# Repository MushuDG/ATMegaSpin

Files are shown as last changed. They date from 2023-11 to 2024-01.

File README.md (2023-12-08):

> [!WARNING]  
> Hey! This project is still a Work in Progress. Files, instructions, and other stuff might change!

# Table of contents
1. [Goal of the game](#goal-of-the-game)
2. [PCB Pictures](#pcb-pictures)
    1. [Front](#front)
    2. [Back](#back)
3. [Schematics](#schematics)
    1. [Electrical schematic](#electrical-schematic)
    2. [PCB schematic](#pcb-schematic)
    3. [Mechanical schematic](#mechanical-schematic)
    4. [ATMega328P Pinout](#atmega328p-pinout)
4. [GERBER - 3D printed Files - Other Hardware stuff](#gerber---3d-printed-files---other-hardware-stuff)
    1. [3D Printed parts](#3d-printed-parts)
    2. [PCB GERBER File](#pcb-gerber-file)
    3. [Electrical parts](#electrical-parts)
5. [Installation](#installation)
    1. [Burn bootloader](#burn-bootloader)
        1. [Needed tools](#needed-tools)
        2. [Circuit](#circuit)
        3. [Pinout](#pinout)
        4. [Upload ISP sketch](#upload-isp-sketch)
        5. [Burn bootloader](#burn-bootloader-1)
            1. [Installing Mini-core](#installing-mini-core)
            2. [Select your device, crystal and programmer and burn bootloader](#select-your-device-crystal-and-programmer-and-burn-bootloader)
    2. [Upload sketch from programmer](#upload-sketch-from-programmer)
6. [Contributions](#contributions)
7. [License](#license)

# ATMegaSpin
## Goal of the game:
A LED game where the player has to press a button at the right moment to reach a specific goal. The challenge of the game lies in the speed at which the LEDs blink, the reduction of this speed with each achieved goal, and the necessity to press the button at the right moment to advance in the game.

## PCB Pictures:
### Front
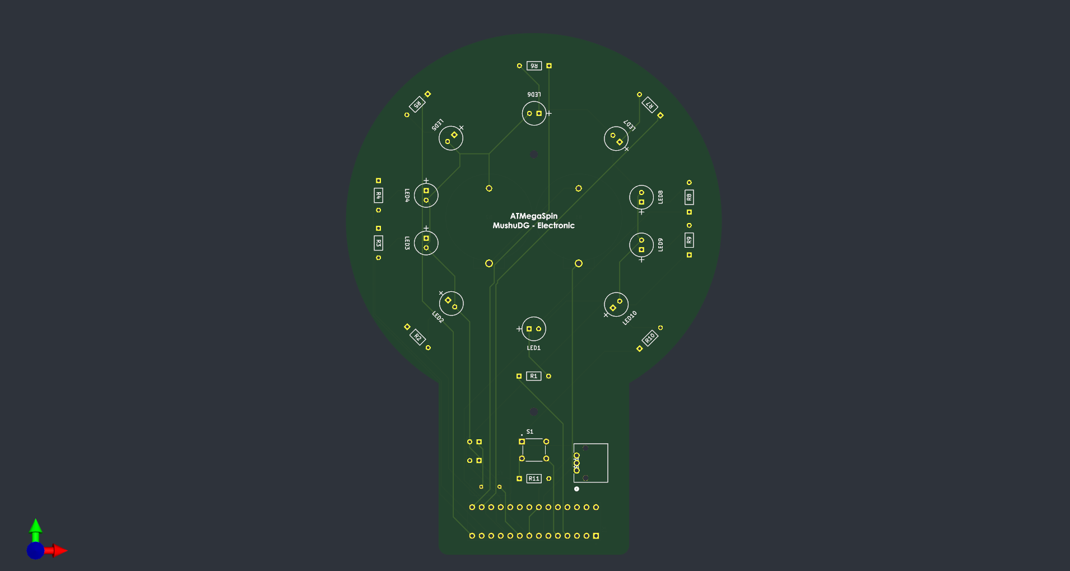
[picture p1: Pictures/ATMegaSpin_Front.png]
Front PCB view

### Back
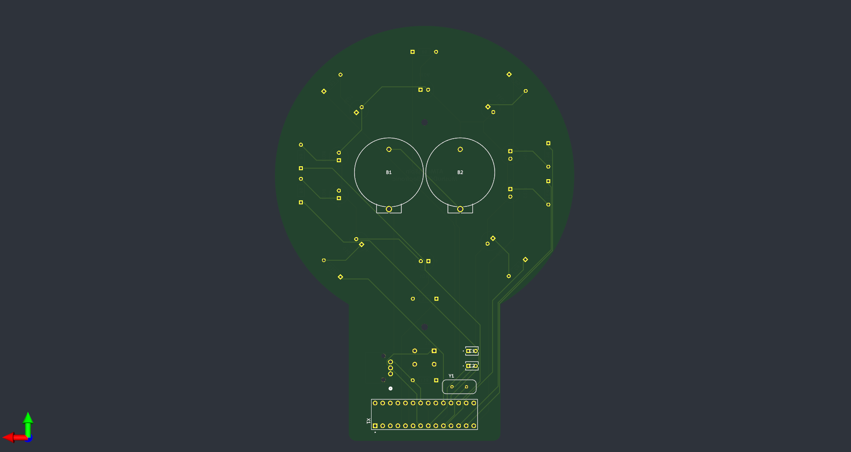
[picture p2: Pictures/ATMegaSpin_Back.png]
Back PCB view


# Schematics
## Electrical schematic:
[Electrical schematic](https://github.com/MushuDG/ATMegaSpin/blob/main/PDF/ATMegaSpin_Schematic.pdf)

## PCB schematic:
[PCB schematic](https://github.com/MushuDG/ATMegaSpin/blob/main/PDF/ATMegaSpin_PCB.pdf)

## Mechanical schematic:
[Mechanical schematic](https://github.com/MushuDG/ATMegaSpin/blob/main/PDF/EnsemblePCB.pdf)

## ATMega328P Pinout:
| Arduino Pinout | Electrical Part | ATMega328 Pinout | ATMega328 Pinout | Electrical Part | Arduino Pinout |
| --- | --- | --- | --- | --- | --- |
| Reset | Not used | 1 | 28 | Not used | A5 |
| D0 RX | Not used | 2 | 27 | Not used | A4 |
| D1 TX | Not used | 3 | 26 | Not used | A3 |
| D2 | LED 1 | 4 | 25 | Not used | A2 |
| D3 | Button Pin 4 | 5 | 24 | Not used | A1 |
| D4 | LED 2 | 6 | 23 | Not used | A0 |
| VCC | +5V | 7 | 22 | GND | GND |
| GND | GND | 8 | 21 | Not used | Aref |
| Crystal | Crystal | 9 | 20 | Not used | Avcc |
| Crystal | Crystal | 10 | 19 | LED 10 | D13 |
| D5 | Not used | 11 | 18 | LED 9 | D12 |
| D6 | LED 3 | 12 | 17 | LED 8 | D11 |
| D7 | LED 4 | 13 | 16 | LED 7 | D10 |
| D8 | LED 5 | 14 | 15 | LED 6 | D9 |

# GERBER - 3D printed Files - Other Hardware stuff
## 3D Printed parts:
[3D Printed parts](https://www.printables.com/fr/model/649943-atmegaspin)

## PCB GERBER File:
[PCB GERBER File](https://github.com/MushuDG/ATMegaSpin/blob/main/KiCad/ATMegaSpin/ATMegaSpin-GERBER.zip)

## Electrical parts:
| N° | PRODUCTS DETAILS | SUPPLIER | QUANTITY | PRICE | TOTAL |
| -- | --- | --- | --- | --- | --- |
| 1  | ED3050-5-ND‎<br>ED281DT‎<br>CONN IC DIP SOCKET 28POS TIN | Digikey  | 5 | Fr. 0.40000 | Fr. 2.00000  |
| 2  | ATMEGA328P-PU-ND‎‎<br>ATMEGA328P-PU‎<br>IC MCU 8BIT 32KB FLASH 28DIP | Digikey  | 5 | Fr. 2.60000 | Fr. 13.00000 |
| 3  | 2223-TS02-66-60-BK-160-SCR-D-ND‎<br>TS02-66-60-BK-160-SCR-D‎<br>6 X 6 MM, 6 MM ACTUATOR HEIGHT, | Digikey  | 5 | Fr. 0.09000 | Fr. 0.45000  |
| 4  | 50-ECS-160-18-4X-CKM-ND‎<br>ECS-160-18-4X-CKM‎<br>CRYSTAL 16.0000MHZ 18PF TH | Digikey  | 5 | Fr. 0.41000 | Fr. 2.05000  |
| 5  | BC1005CT-ND‎<br>‎K220J15C0GF5TL2‎<br>CAP CER 22PF 50V C0G/NP0 RADIAL | Digikey  | 10 | Fr. 0.15500 | Fr. 1.55000  |
| 6  | BS-7-ND‎<br>BS-7‎<br>BATT HLDR COIN 20MM 1 CEL PC PIN | Digikey  | 10 | Fr. 0.84100 | Fr. 8.41000  |
| 7  | CF18JT200RCT-ND‎<br>‎CF18JT200R‎<br>RES 200 OHM 5% 1/8W AXIAL | Digikey  | 50 | Fr. 0.02260 | Fr. 1.13000  |
| 8  | ‎516-1325-ND‎<br>‎HLMP-4700‎<br>LED RED DIFFUSED T-1 3/4 T/H | Digikey  | 50 | Fr. 0.34600 | Fr. 17.30000 |
| 9  | MFS101D-6-Z | Digikey  | 5 | Fr. 1.52000 | Fr. 7.60000  |
| 10 | PCB JLCPCB | JLCPCB | 5 | Fr. 1.84000 | Fr. 9.20000  |
| | | | | | |
| | Aprox. Total | | | | Fr. 62.69 |
| | Aprox. Total/pcs | | | | Fr. 12.54 |

# Prototype
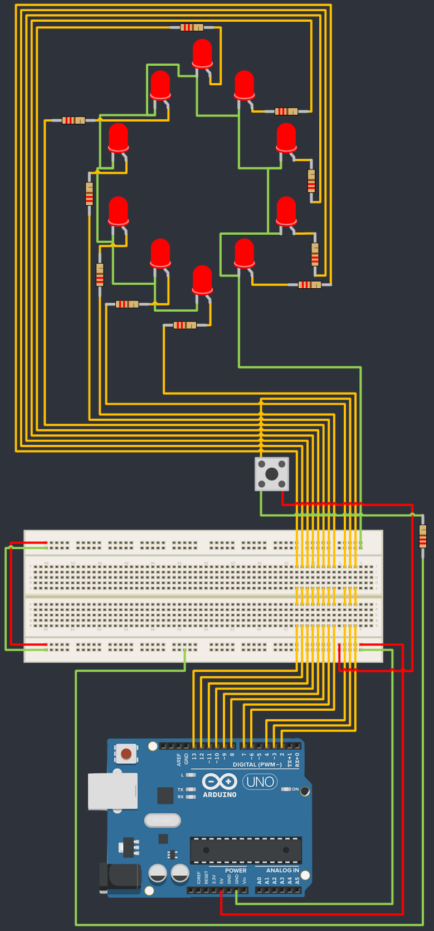
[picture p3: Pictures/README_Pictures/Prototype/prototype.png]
Prototype


# Installation
Before you can connect the [ATMega328P](https://en.wikipedia.org/wiki/ATmega328) microcontroller to the circuit, it's necessary to burn the bootloader of the chip. Once the bootloader is burned, the program can be uploaded to it.

*"To program the bootloader and provide to the microcontroller the compatibility with the Arduino Software (IDE) you need to use an In-circuit Serial Programmer (ISP) that is the device that connects to a specific set of pins of the microcontroller to perform the programming of the whole flash memory of the microcontroller, bootloader included. The ISP programming procedure also includes the writing of fuses: a special set of bits that define how the microcontroller works under specific circumstances."*

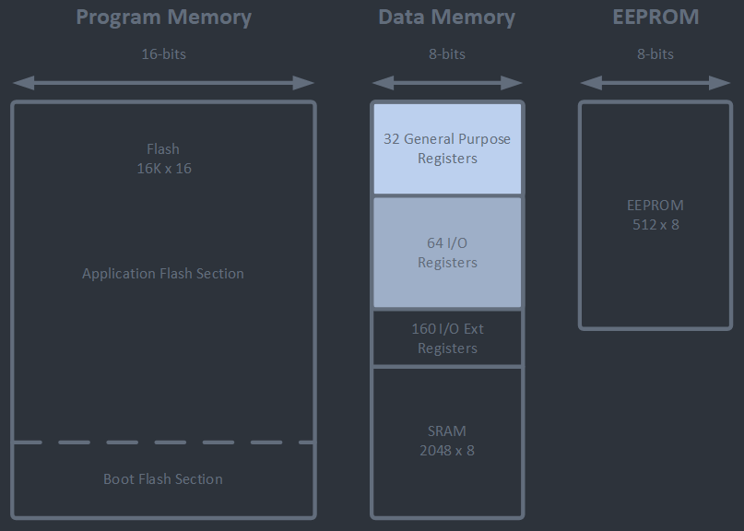
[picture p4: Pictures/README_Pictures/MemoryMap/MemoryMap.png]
Memory Map

The Memory Map of an ATmega328P

> [!IMPORTANT]  
> The preceding paragraph and illustration were taken from this documentation: [Arduino as ISP and Arduino Bootloaders](https://docs.arduino.cc/built-in-examples/arduino-isp/ArduinoISP) -  Accessed on 2023-11-22

## Burn bootloader
### Needed tools
To burn the bootloader on the microcontroller you need 2 arduino (In this case I use Arduino UNO) cards. The first will be used as an ISP programmer.

### Circuit
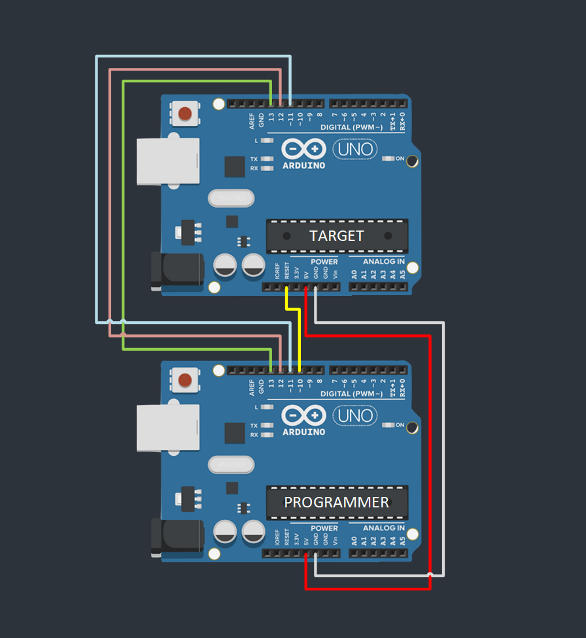
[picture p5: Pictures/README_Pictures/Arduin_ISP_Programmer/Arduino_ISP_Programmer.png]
Arduino ISP Programmer circuit


### Pinout
| Arduino Programmer Pin | Arduino Target Pin |
| --- | --- |
| +5 [V] | +5 [V] |
| GND | GND |
| D10 | Reset |
| 11 | 11 |
| 12 | 12 |
| 13 | 13 |

### Upload ISP sketch
Once the circuit is connected, follow the following instructions to apply the ISP programming sketch on the Arduino programmer:
1. Open the Arduino IDE and from the menu *File > Examples > 11.ArduinoISP > ArduinoISP*, load the sketch.
2. Select the proper board (I.E.: Arduino Uno) and upload the sketch

### Burn bootloader
#### Installing Mini-core
1. Open up the Arduino IDE and navigate to the preferences (or press ctrl+,). Copy the following URL into the empty field labelled *‘Additional Boards Manager URLs’*: [https://mcudude.github.io/MiniCore/package_MCUdude_MiniCore_index.json](https://mcudude.github.io/MiniCore/package_MCUdude_MiniCore_index.json)
2. Go to the boards manager, which can be found under *Tools > Board > Boards Manager*.
Type *‘minicore’* into the search bar and the relevant entry will appear. Select the latest version and click *‘install’*. Once the installation is complete, close the boards manager window.

#### Select your device, crystal and programmer and burn bootloader
1. Select the relevant device, crystal and programmer options under the *‘tools’* menu.
2. Under board, select *‘ATmega328’* (or whichever chip you’re using).
3. Under clock, select the frequency of your external clock. It should be written in block capitals on the top of the crystal’s casing.
4. Set your programmer as *‘Arduino as ISP’*
5. Burn the bootloader using the *‘Burn Bootloader’* option at the bottom of the Tools menu.

## Upload sketch from programmer
Once the bootloader is burned, open up the *[Spin.ino](https://github.com/MushuDG/ATMegaSpin/blob/main/Code/Spin/Spin.ino)* sketch. From the menu *Sketch* use the *Upload Using Programmer* tool to Upload the sketch to the ATMega328P Target.

Then, you can disconnect the MCU from the Arduino target and clip it to your circuit. 

## Contributions

Contributions to this project are welcome! If you have ideas for improvements or bug fixes, please follow the [contribution guidelines](CONTRIBUTING.md).

1. Fork the project.
2. Create your feature branch: `git checkout -b feature/AmazingFeature`.
3. Commit your changes: `git commit -m 'Add some amazing feature'`.
4. Push to the branch: `git push origin feature/AmazingFeature`.
5. Open a pull request.

## License

This project is licensed under the  AGPL-3.0 license - see the [LICENSE](LICENSE) file for details.

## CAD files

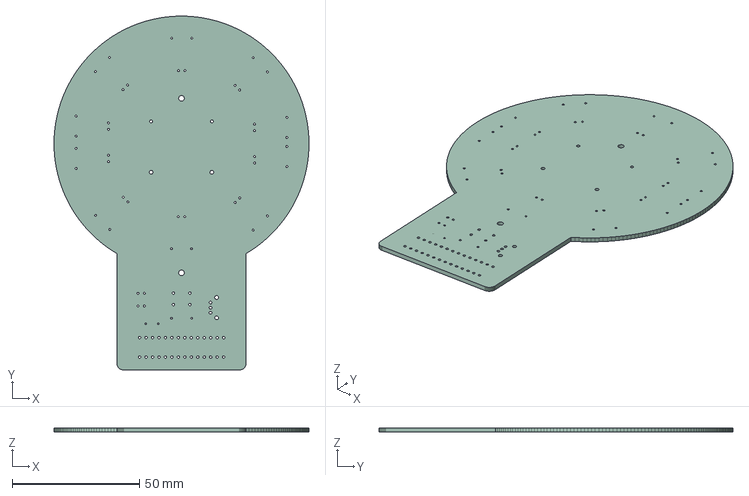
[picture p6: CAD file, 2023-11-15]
3DModel/ATMegaSpin.step
100.2 x 139.0 x 1.60 mm

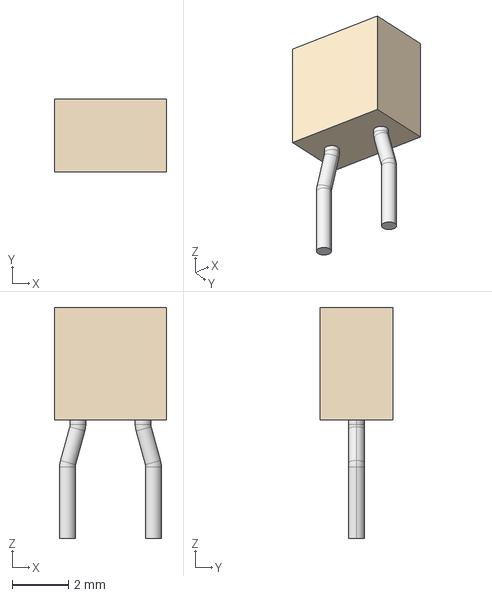
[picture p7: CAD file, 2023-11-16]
3DModel/Parts/CAP_K-SERIES_15-L2_VIS.step
3.99 x 2.59 x 8.20 mm

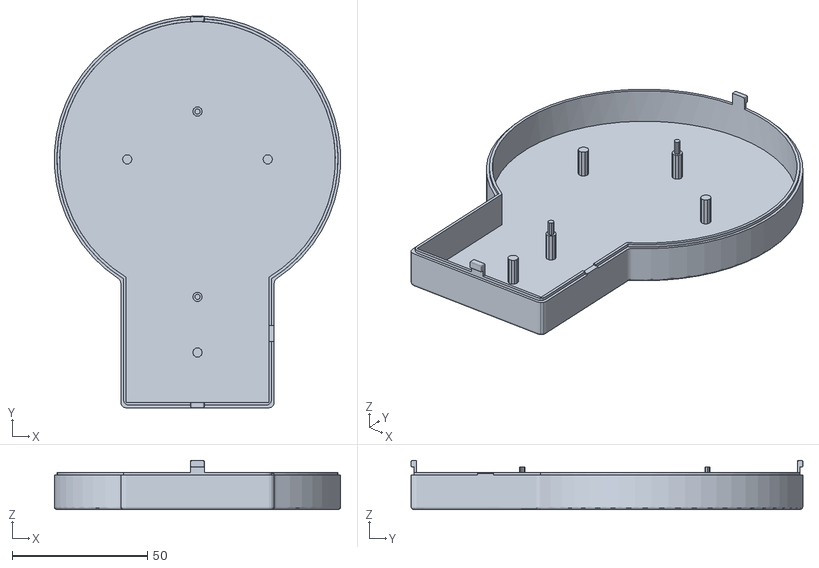
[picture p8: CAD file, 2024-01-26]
Inventor/STL/BottomBox.stl
105.8 x 145.0 x 18.2

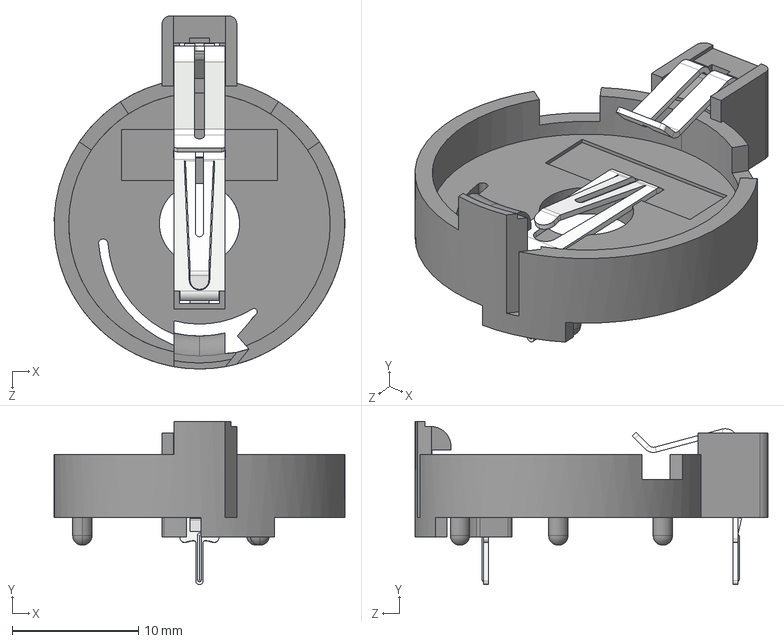
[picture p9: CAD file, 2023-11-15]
KiCad/ATMegaSpin/1066/1066.step
23.0 x 12.9 x 27.9 mm

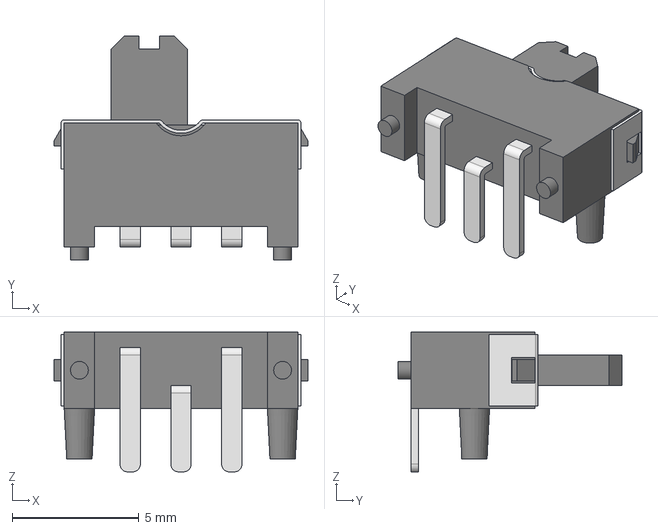
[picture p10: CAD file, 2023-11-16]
3DModel/Parts/MFS101D-6-Z.stp
10.0 x 8.80 x 5.50 mm
MFS101D61_bu
MFS101D-6-Z_b

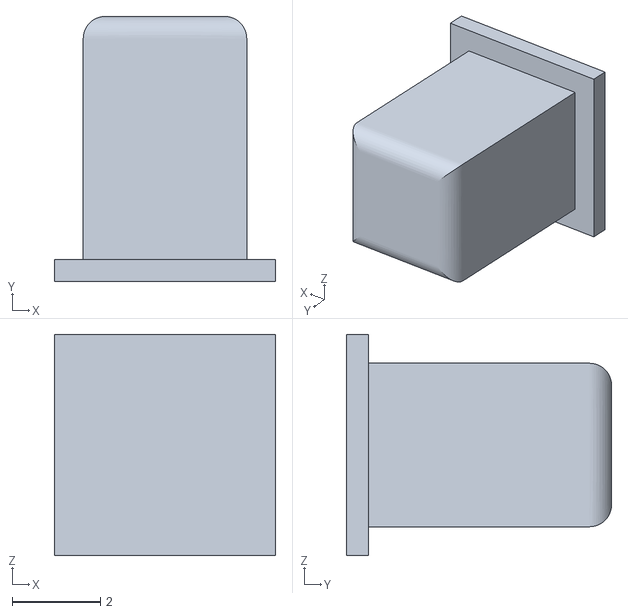
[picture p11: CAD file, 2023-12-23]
Inventor/button v3.stl
5.00 x 6.00 x 5.00

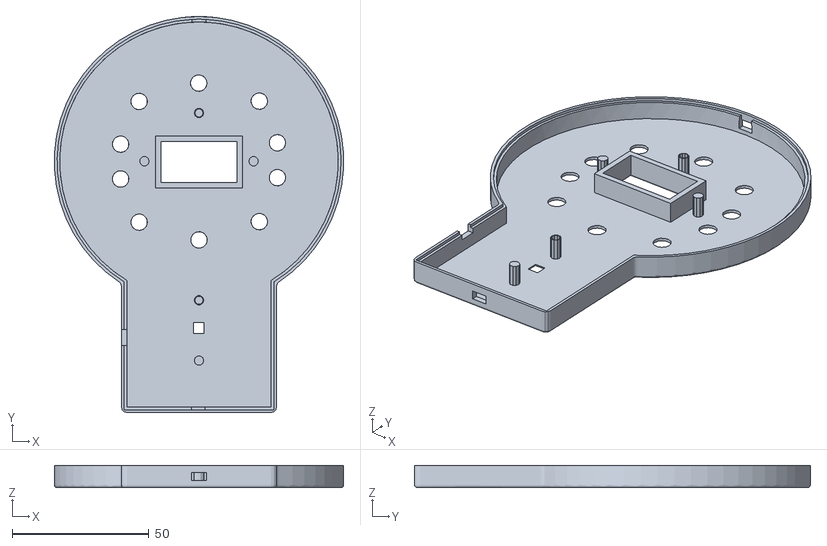
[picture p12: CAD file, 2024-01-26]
Inventor/STL/TopBox.stl
105.8 x 145.0 x 8.20

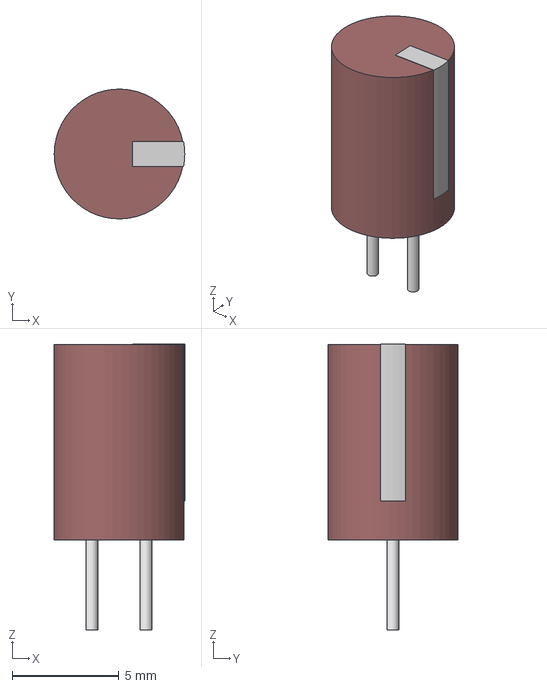
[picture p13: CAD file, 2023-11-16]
3DModel/Parts/LED_HLMP-47XX_BRA.step
6.13 x 6.09 x 13.4 mm

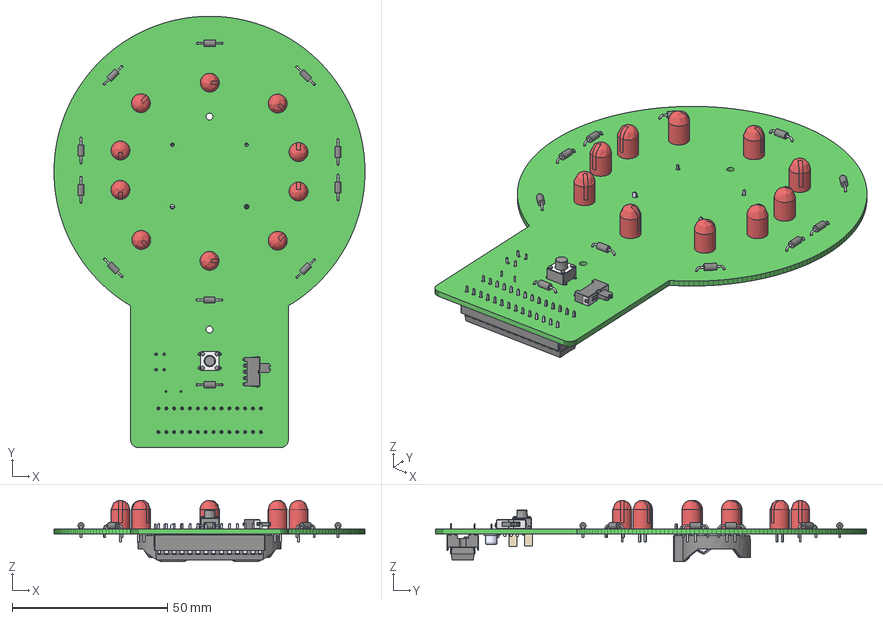
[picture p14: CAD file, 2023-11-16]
Inventor/EnsemblePCB.stp
100.2 x 139.0 x 19.8 mm
ATMegaSpin
BS-7 x 2
ED281DT
ATMEGA328-PU
ECS-80-18-4XDN
product
product_1
product_2 x 11
product_3 x 10
CUI_DEVICES_TS02-66-60-BK-160-SCR-D
MFS101D-6-Z

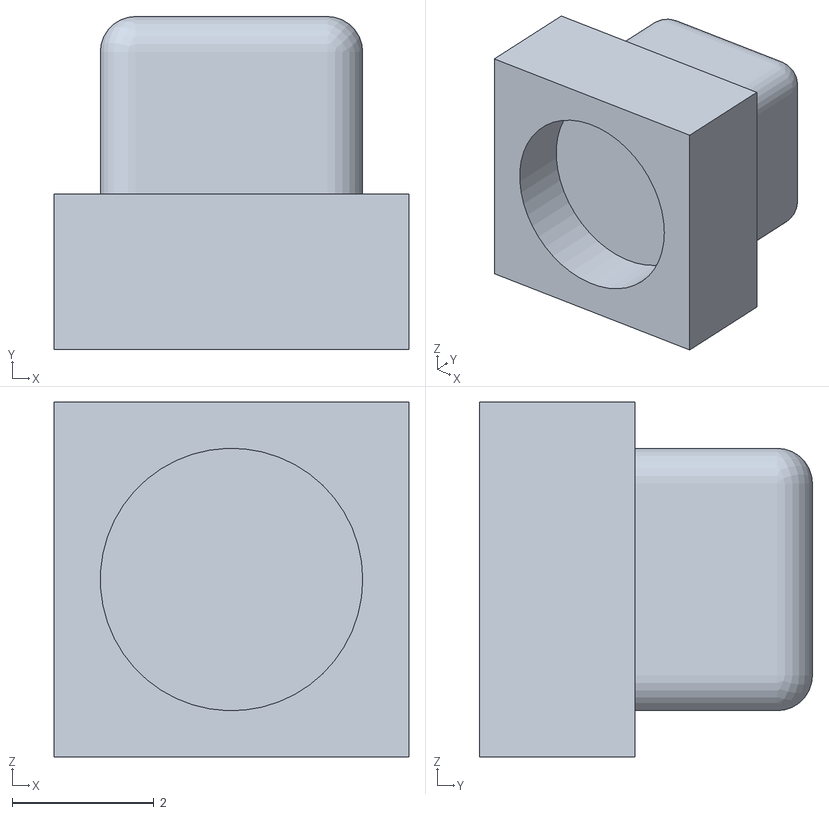
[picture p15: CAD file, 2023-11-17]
Inventor/STL/button.stl
5.00 x 4.70 x 5.00

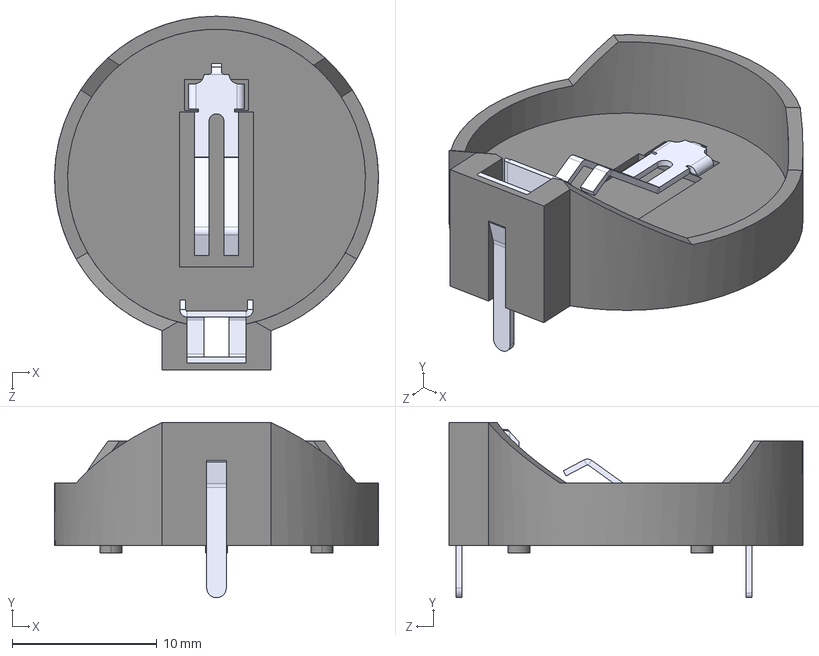
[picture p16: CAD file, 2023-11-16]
3DModel/Parts/BS-7--3DModel-STEP-1.STEP
22.3 x 12.1 x 24.4 mm

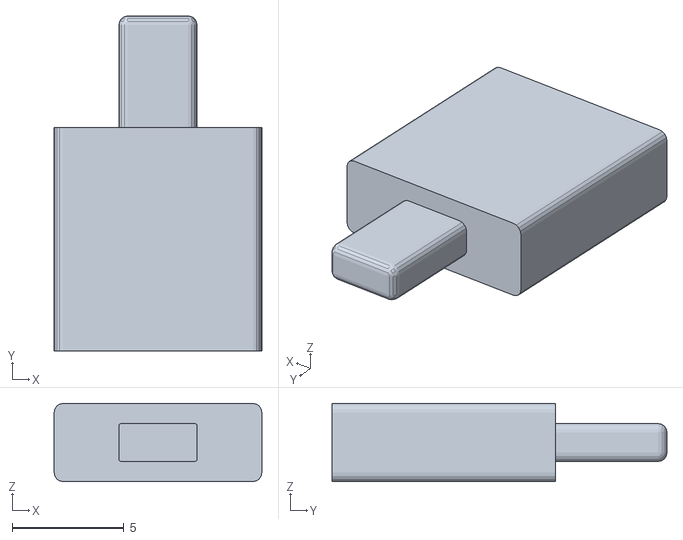
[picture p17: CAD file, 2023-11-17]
Inventor/STL/SwitchOnOff.stl
9.30 x 15.0 x 3.50

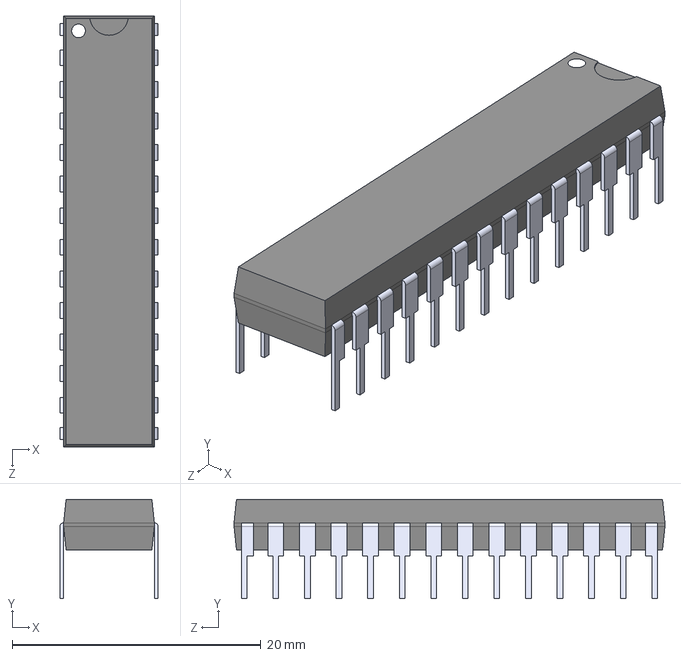
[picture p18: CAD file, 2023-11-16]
3DModel/Parts/ATMEGA328P-PU.step
7.90 x 8.00 x 34.7 mm

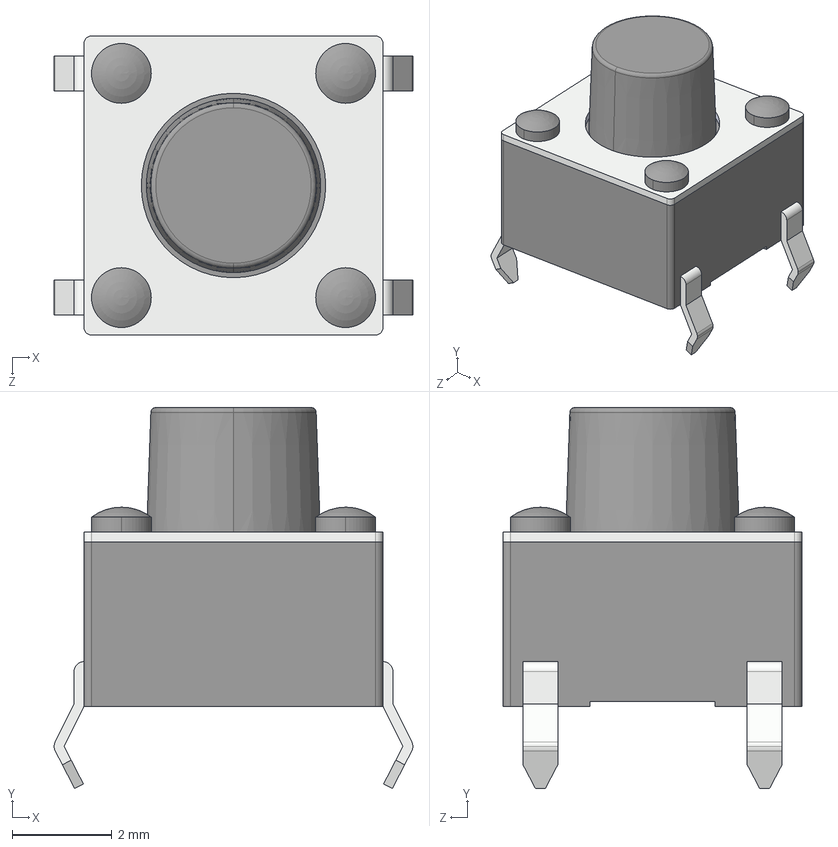
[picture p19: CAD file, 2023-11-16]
3DModel/Parts/CUI_DEVICES_TS02-66-60-BK-160-SCR-D.step
7.20 x 7.65 x 6.00 mm

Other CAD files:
3DModel/Parts/STA_CF18_STP.step
3DModel/Parts/ECS-160-18-4X-CKM.step
3DModel/Parts/ED281DT.step
Inventor/button v2.stl
3DModel/ATMegaSpin/ATMegaSpin.ipt
3DModel/Parts/ATMEGA328P-PU/ATMEGA328P-PU.ipt
3DModel/Parts/BS-7--3DModel-STEP-1/BS-7--3DModel-STEP-1.ipt
3DModel/Parts/CAP_K-SERIES_15-L2_VIS/CAP_K-SERIES_15-L2_VIS.ipt
3DModel/Parts/CUI_DEVICES_TS02-66-60-BK-160-SCR-D/CUI_DEVICES_TS02-66-60-BK-160-SCR-D.ipt
3DModel/Parts/ECS-160-18-4X-CKM/ECS-160-18-4X-CKM.ipt
3DModel/Parts/ED281DT/ED281DT.ipt
3DModel/Parts/LED_HLMP-47XX_BRA/LED_HLMP-47XX_BRA.ipt
3DModel/Parts/MFS101D-6-Z/MFS101D-6-Z.ipt
3DModel/Parts/STA_CF18_STP/STA_CF18_STP.ipt
Inventor/BottomBox.ipt
Inventor/Ensemble2.iam
Inventor/EnsemblePCB.dwg
Inventor/EnsemblePCB.iam
Inventor/EnsemblePCB/EnsemblePCB.ipt
Inventor/OldVersions/BottomBox.0009.ipt
Inventor/OldVersions/Ensemble1.0001.iam
Inventor/OldVersions/Ensemble2.0010.iam
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

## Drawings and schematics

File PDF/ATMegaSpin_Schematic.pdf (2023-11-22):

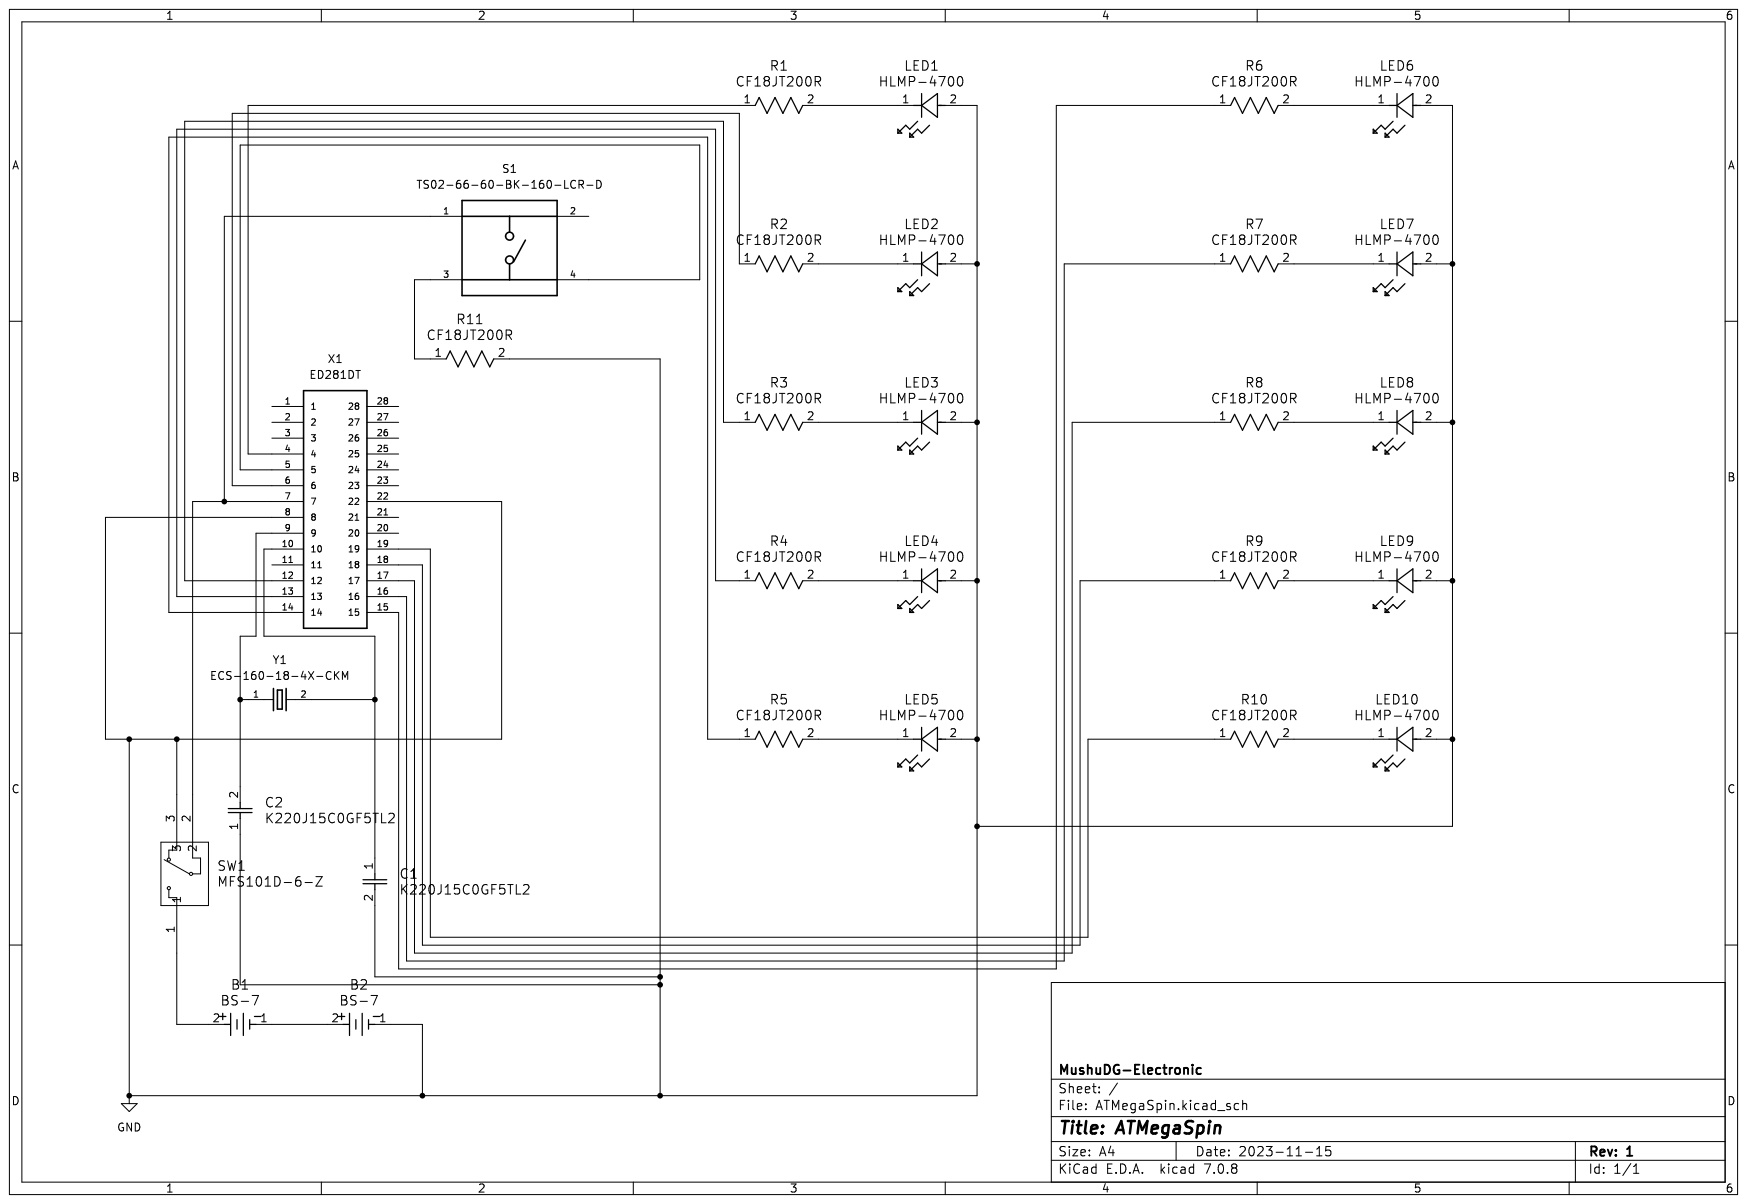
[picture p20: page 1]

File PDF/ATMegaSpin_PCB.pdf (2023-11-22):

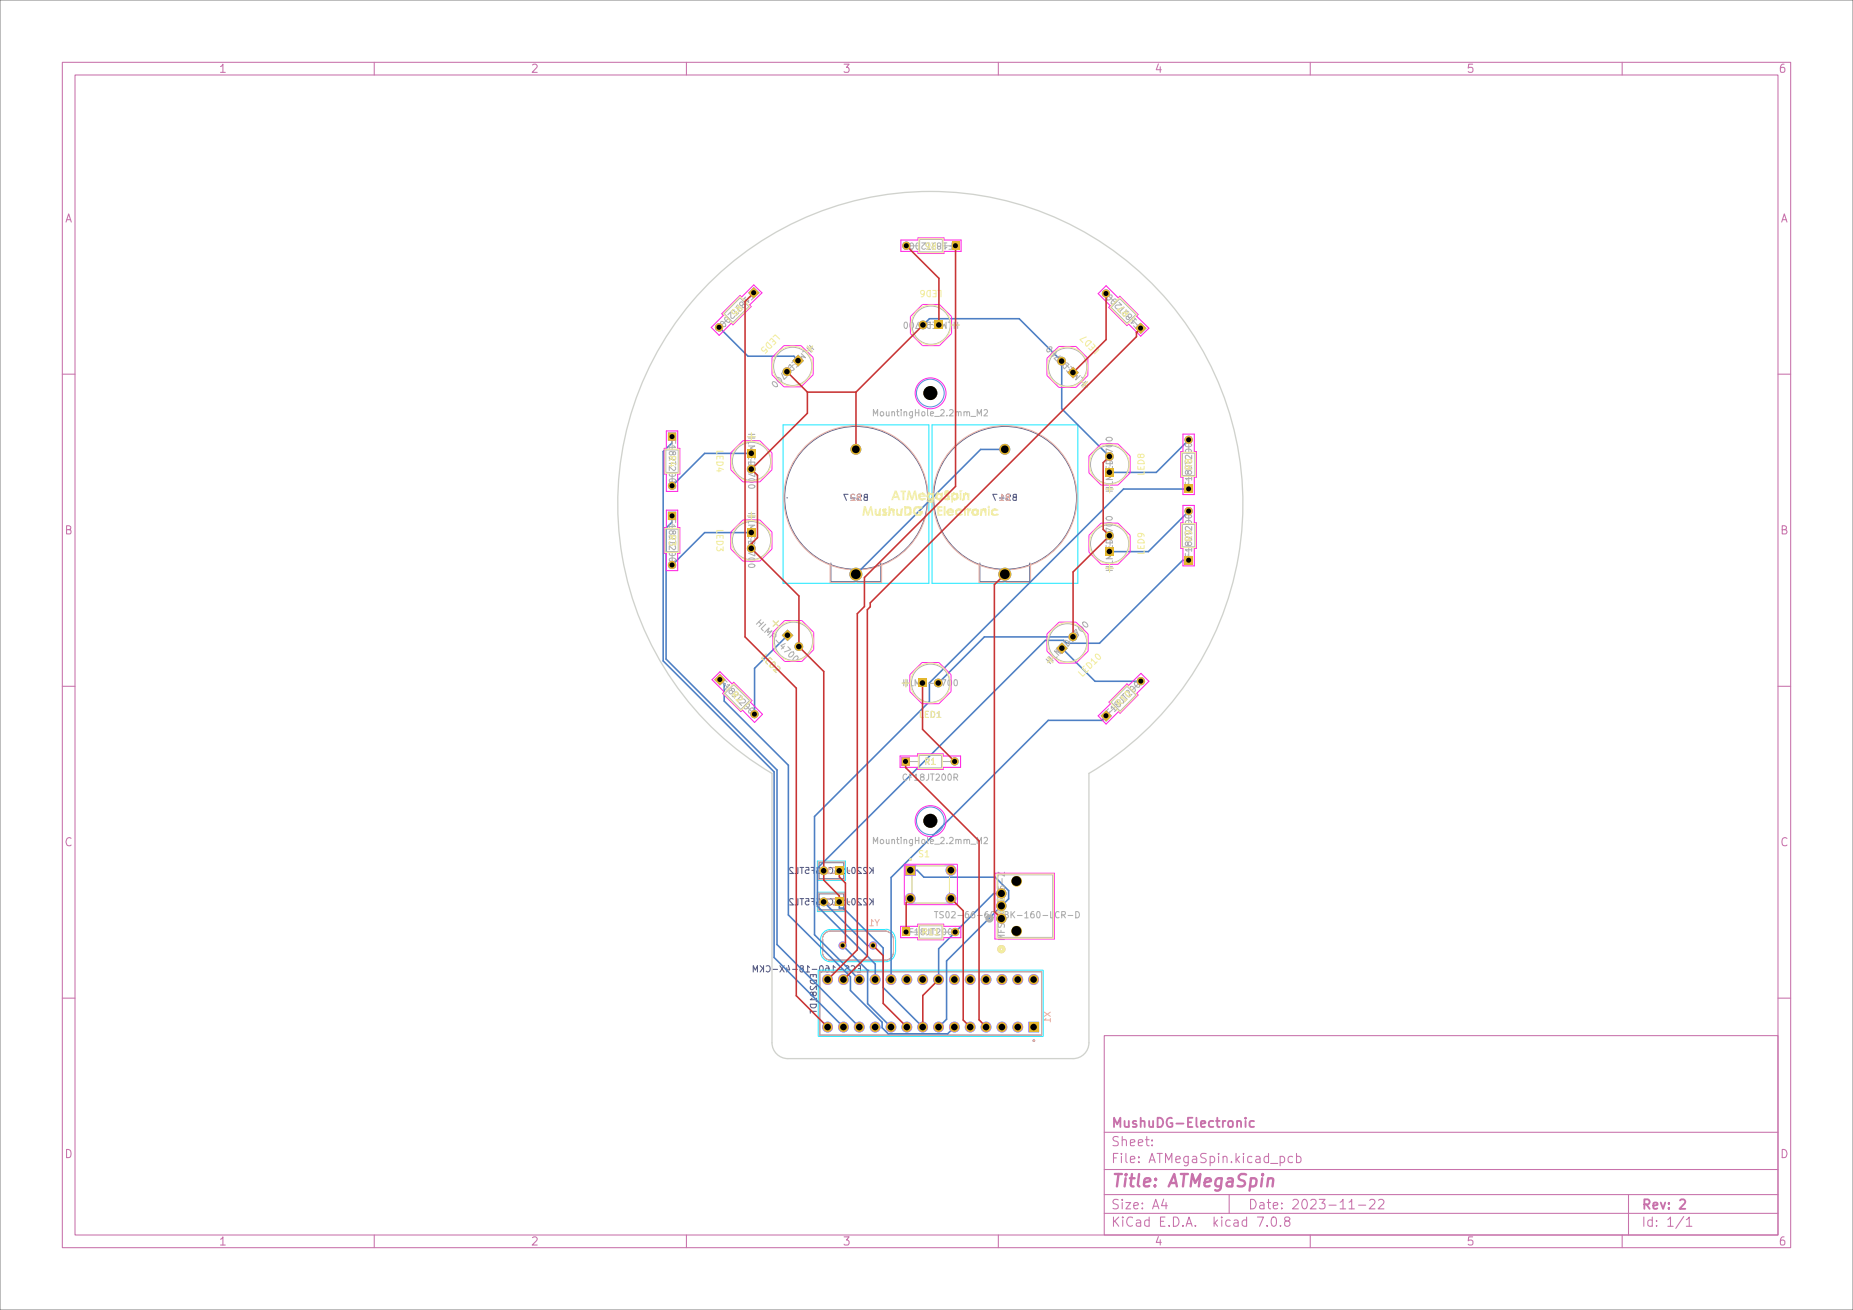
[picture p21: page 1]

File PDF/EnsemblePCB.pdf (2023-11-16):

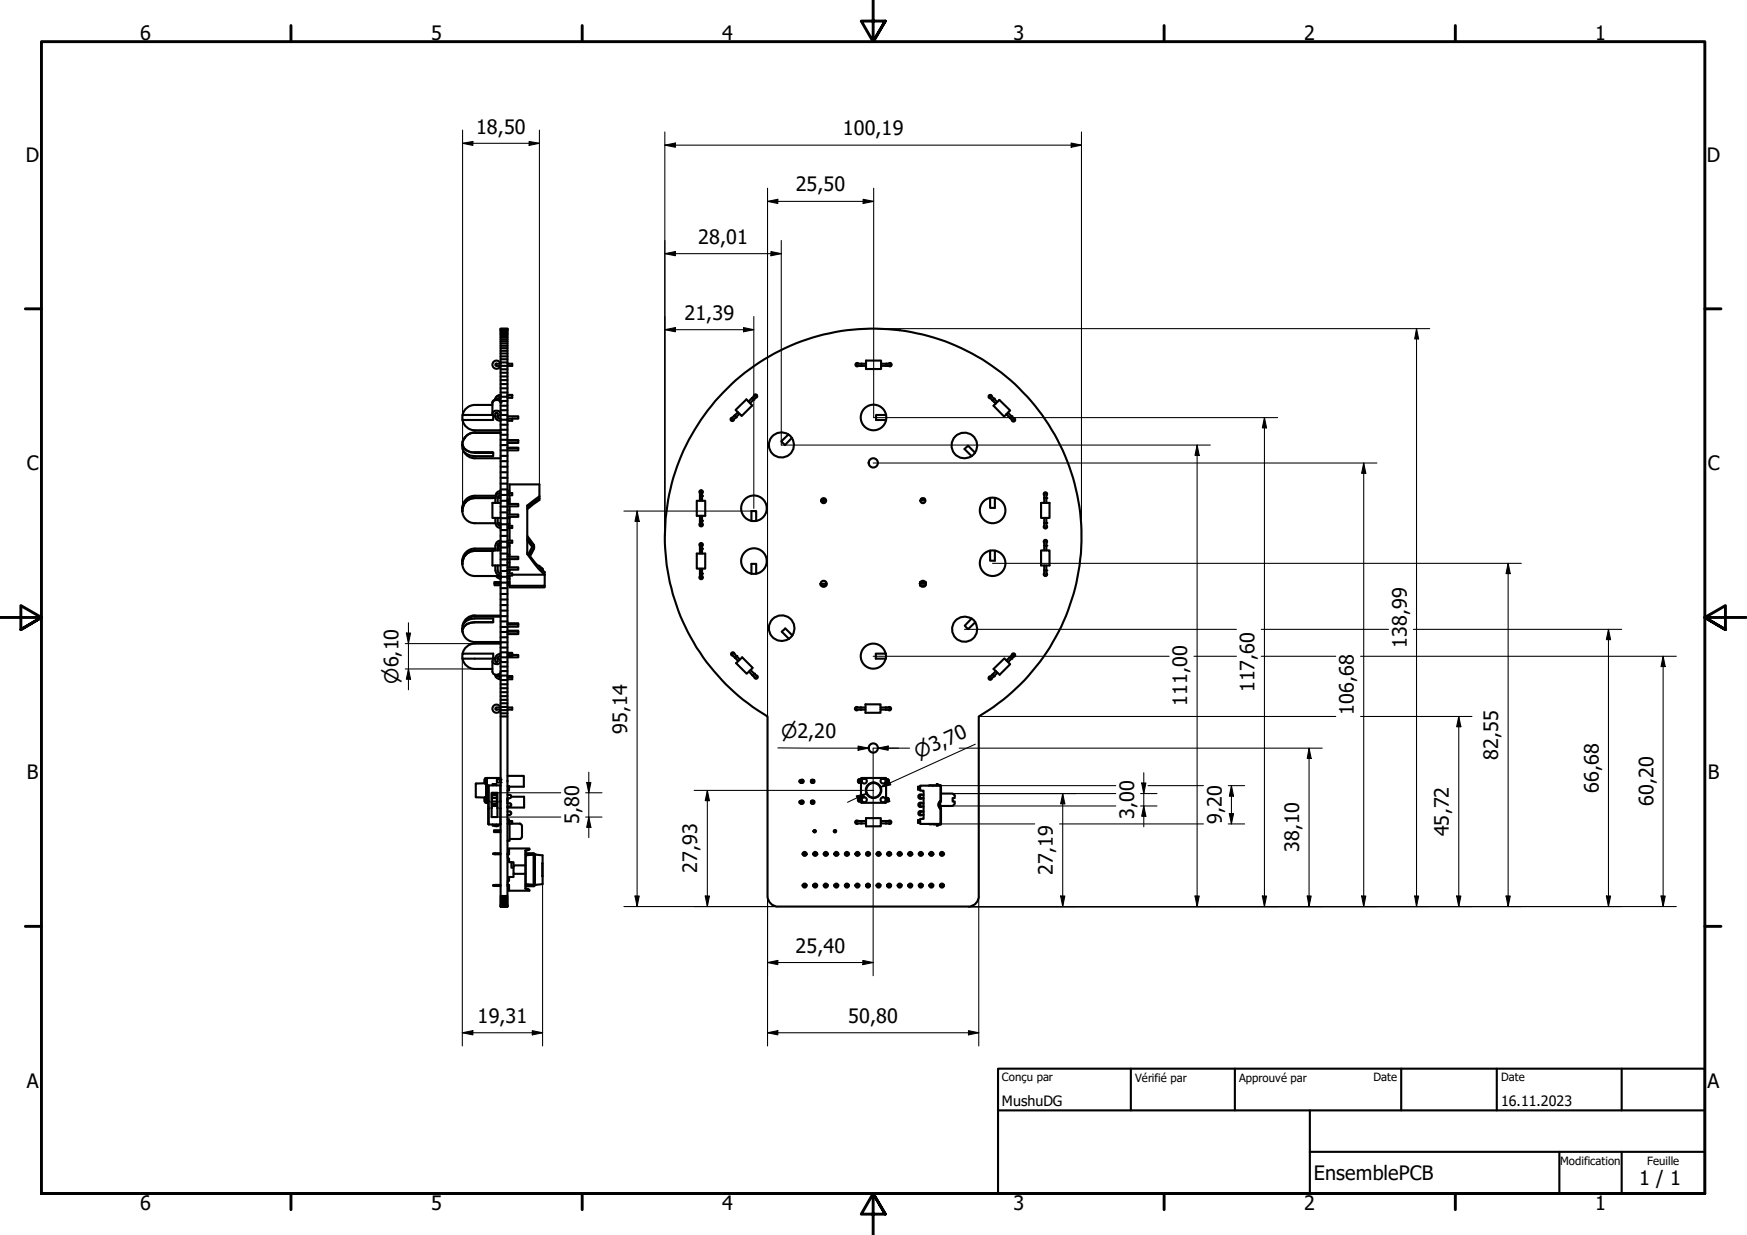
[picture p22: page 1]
Conçu par; Vérifié par; Approuvé par; Date

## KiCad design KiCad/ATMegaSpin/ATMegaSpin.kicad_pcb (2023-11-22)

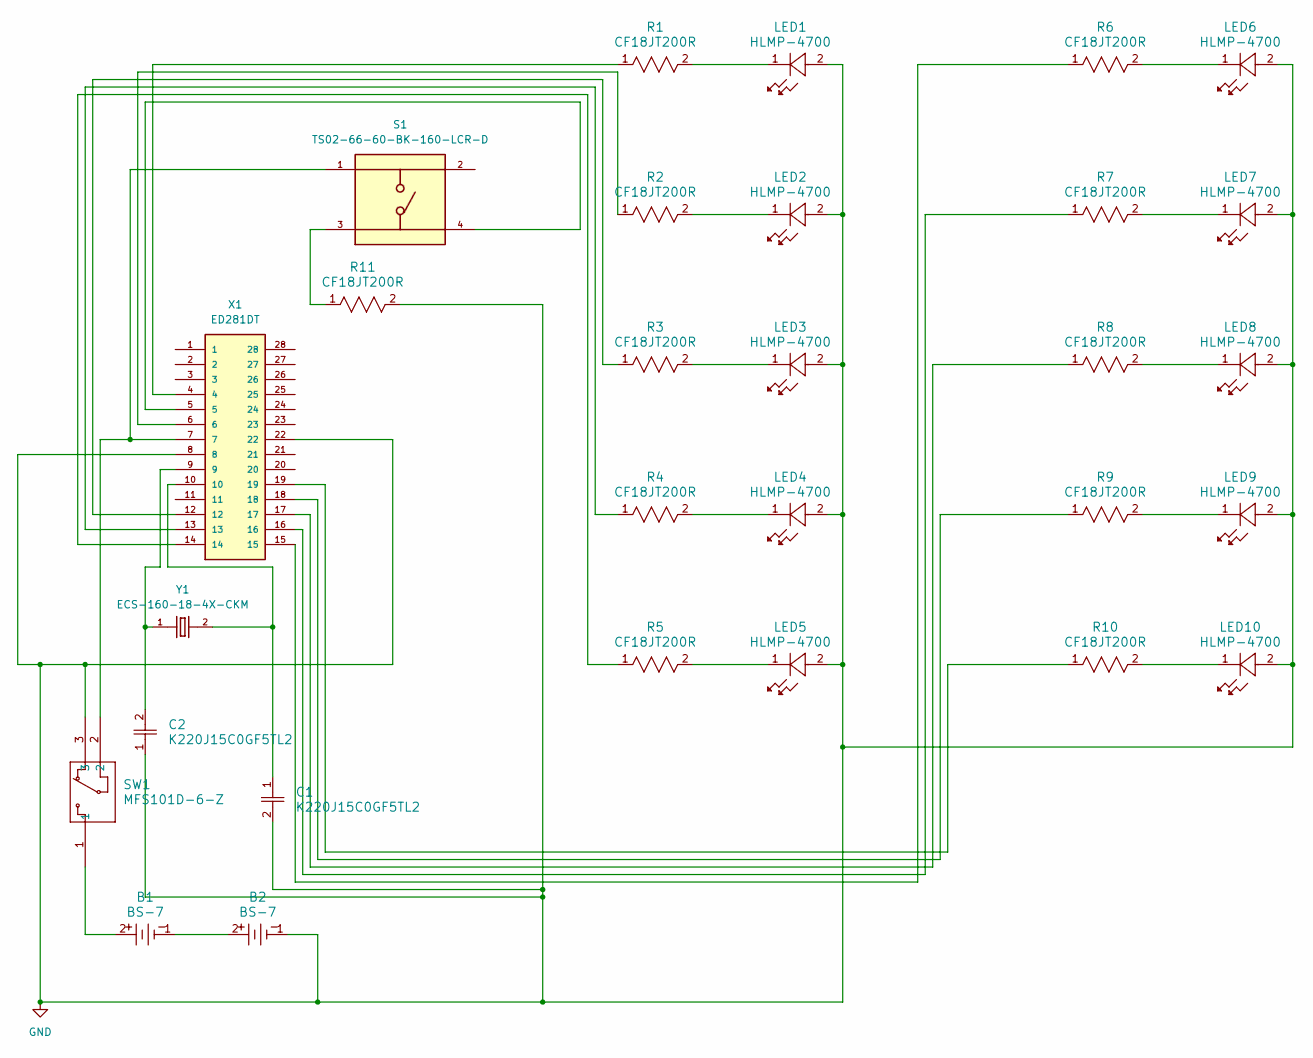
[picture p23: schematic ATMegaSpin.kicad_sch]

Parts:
B1, B2: BS-7; BS-7_MPD
C1, C2: K220J15C0GF5TL2; CAP_K-SERIES_15-L2_VIS
LED1, LED2, LED3, LED4, LED5, LED6, LED7, LED8, LED9, LED10: HLMP-4700; LED_HLMP-47XX_BRA
R1, R2, R3, R4, R5, R6, R7, R8, R9, R10, R11: CF18JT200R; STA_CF18_STP
S1: TS02-66-60-BK-160-LCR-D; SW_TS02-66-60-BK-160-LCR-D; PARTREV 1.0
SW1: MFS101D-6-Z; MFS101D-6-Z_NDC
X1: ED281DT; OST_ED281DT; PARTREV D
Y1: ECS-160-18-4X-CKM; XTAL_ECS-160-18-4X-CKM

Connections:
GND: B2.1, C1.2, C2.1, LED1.2, LED2.2, LED3.2, LED4.2, LED5.2, LED6.2, LED7.2, LED8.2, LED9.2, LED10.2, R11.2, SW1.3, X1.8, X1.22
unnamed: B1.1, B2.2
unnamed: B1.2, SW1.1
unnamed: C1.1, X1.10, Y1.2
unnamed: C2.2, X1.9, Y1.1
unnamed: LED1.1, R1.2
unnamed: LED2.1, R2.2
unnamed: LED3.1, R3.2
unnamed: LED4.1, R4.2
unnamed: LED5.1, R5.2
unnamed: LED6.1, R6.2
unnamed: LED7.1, R7.2
unnamed: LED8.1, R8.2
unnamed: LED9.1, R9.2
unnamed: LED10.1, R10.2
unnamed: R1.1, X1.4
unnamed: R2.1, X1.6
unnamed: R3.1, X1.12
unnamed: R4.1, X1.13
unnamed: R5.1, X1.14
unnamed: R6.1, X1.15
unnamed: R7.1, X1.16
unnamed: R8.1, X1.17
unnamed: R9.1, X1.18
unnamed: R10.1, X1.19
unnamed: R11.1, S1.3
unnamed: S1.1, SW1.2, X1.7
unnamed: S1.4, X1.5

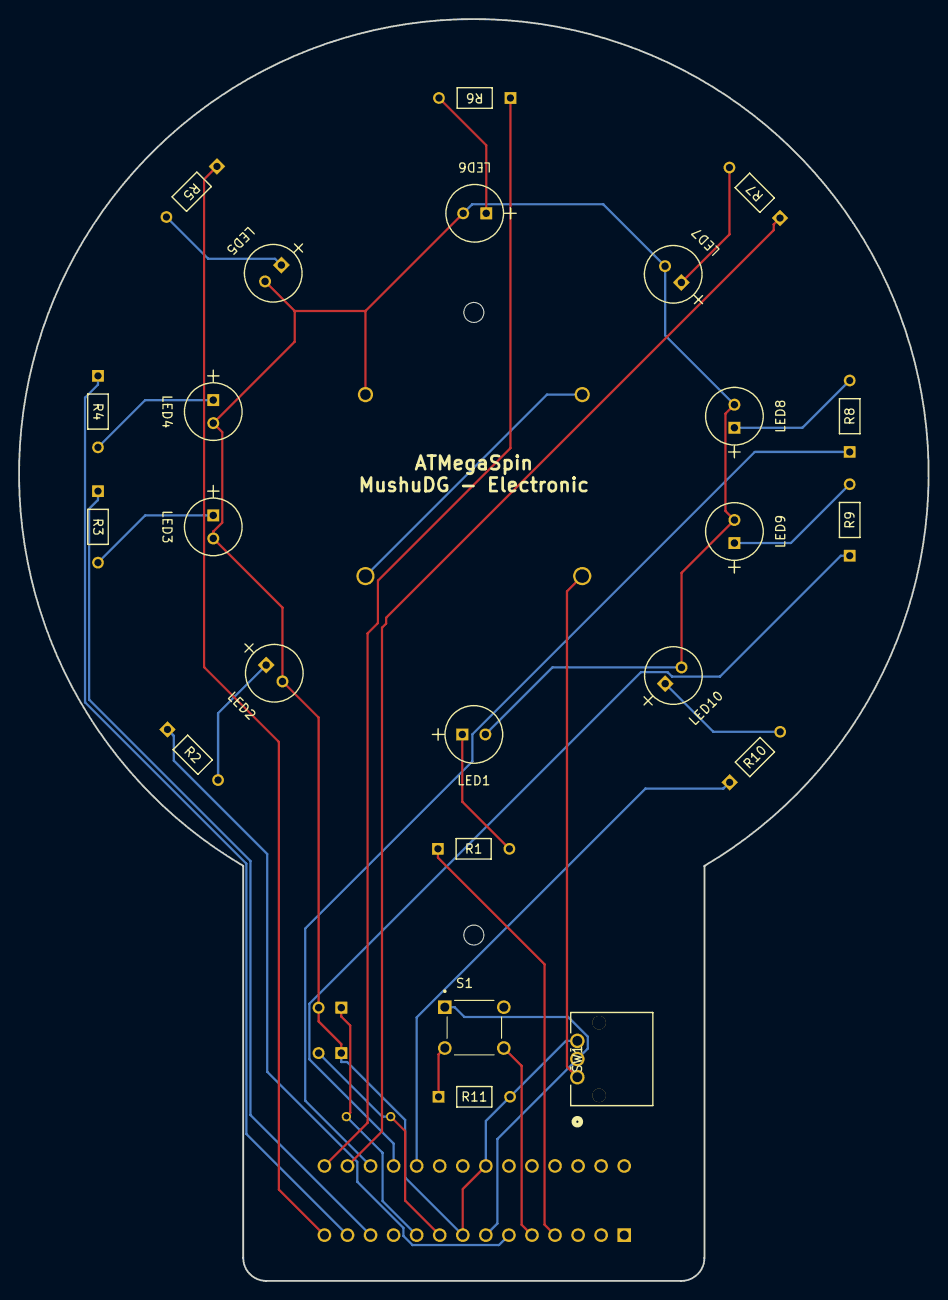
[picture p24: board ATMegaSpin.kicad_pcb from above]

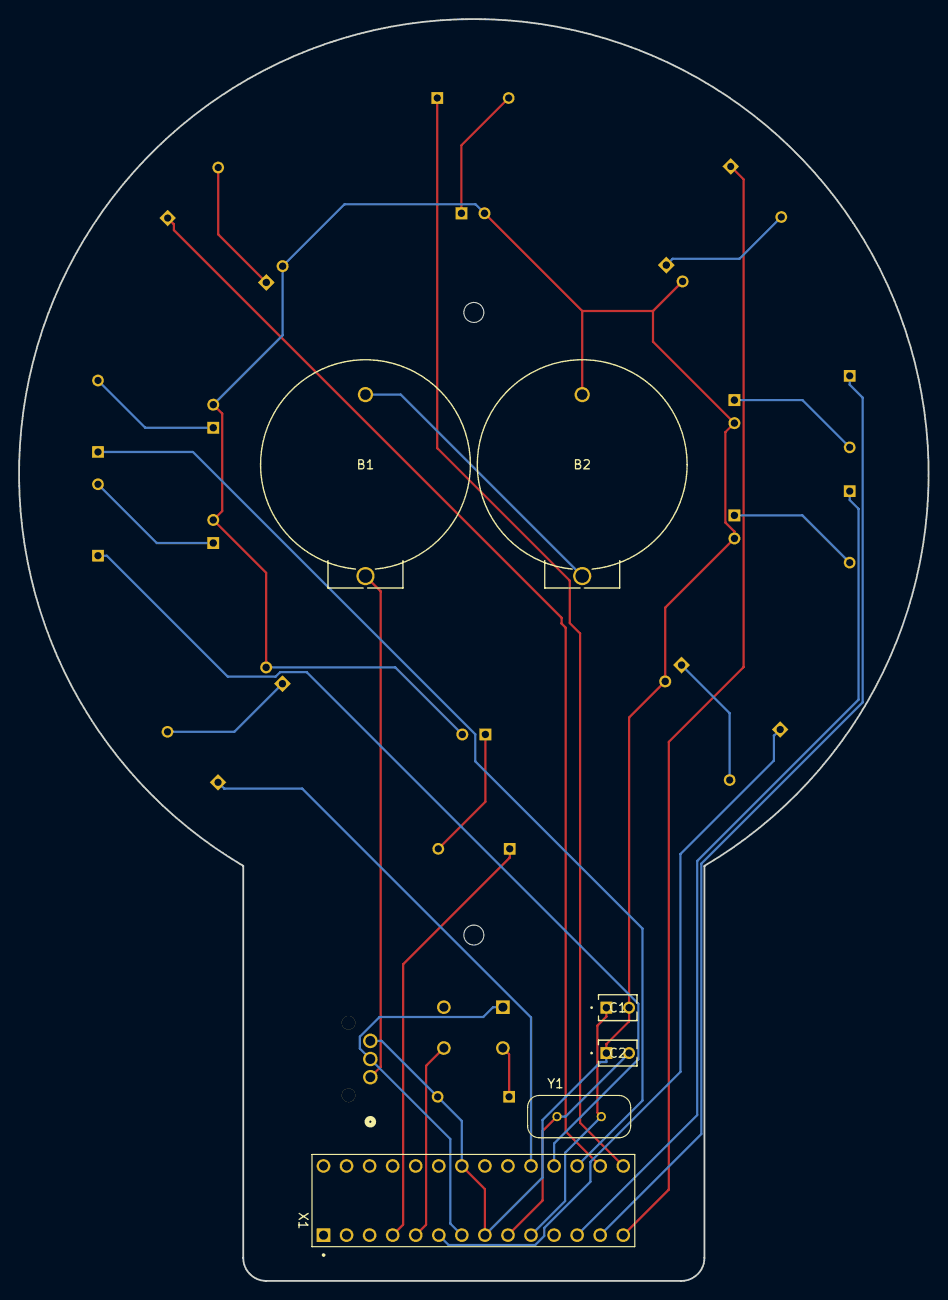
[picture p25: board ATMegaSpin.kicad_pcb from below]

Board: 2 copper layers, 100.2 x 139.0 mm, 31 parts (6 on the bottom side), 28 nets.

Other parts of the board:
H: MountingHole_2.2mm_M2
h2: MountingHole_2.2mm_M2

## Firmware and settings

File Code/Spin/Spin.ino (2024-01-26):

////////////////////////////////////////////////////////////////////////////////
// General informations
////////////////////////////////////////////////////////////////////////////////
// Author:             Mushu
// Project:            ATMegaSpin
// File:               Spin.ino
// Creation date:      14 novembre 2023
// Description:        Program managing the game
////////////////////////////////////////////////////////////////////////////////
////////////////////////////////////////////////////////////////////////////////
// Pin Declaration
////////////////////////////////////////////////////////////////////////////////
// Declaration of pin numbers
#define LED_PIN_0                       2                                       // LED 0
#define LED_PIN_1                       4                                       // LED 1
#define LED_PIN_2                       6                                       // LED 2
#define LED_PIN_3                       7                                       // LED 3
#define LED_PIN_4                       8                                       // LED 4
#define LED_PIN_5                       9                                       // LED 5
#define LED_PIN_6                       10                                      // LED 6
#define LED_PIN_7                       11                                      // LED 7
#define LED_PIN_8                       12                                      // LED 8
#define LED_PIN_9                       13                                      // LED 9
#define BUTTON_PIN_PLAY                 3                                       // BUTTON PLAY
//#define buttonPinReset                5                                       // BUTTON RESET

////////////////////////////////////////////////////////////////////////////////
// Constants
////////////////////////////////////////////////////////////////////////////////
const int LED_NUMBER PROGMEM    =       10;                                     // TOTAL LED count
const int MAX_SPEED PROGMEM     =       1500;                                   // Define max speed game
const int MIN_SPEED PROGMEM     =       500;                                    // Define min speed game

////////////////////////////////////////////////////////////////////////////////
// Array of LED Pins
////////////////////////////////////////////////////////////////////////////////
const byte LEDPinArray[LED_NUMBER]  =   {   LED_PIN_0,
                                            LED_PIN_1,
                                            LED_PIN_2,
                                            LED_PIN_3,
                                            LED_PIN_4,
                                            LED_PIN_5,
                                            LED_PIN_6,
                                            LED_PIN_7,
                                            LED_PIN_8,
                                            LED_PIN_9
                                        };      

////////////////////////////////////////////////////////////////////////////////
// Variables
////////////////////////////////////////////////////////////////////////////////
int buttonPlayState             =       0;                                      // Var for reading the pushbutton play status
//int buttonResetState          =       0;                                      // Var for reading the pushbutton reset status
int ledState                    =       0;                                      // Var for reading the led status
int score                       =       0;                                      // Score
int goal                        =       10;                                     // Goal to reached
float delaySpeed                =       0;                                      // Define the speed game
float subtractValue             =       0;                                      // Define the subtract speed value
bool exitFlag                   =       false;                                  // Exit loop flag

////////////////////////////////////////////////////////////////////////////////
// Function Prototypes
////////////////////////////////////////////////////////////////////////////////
void setup();
void loop();
void Start_Waiting();
void Starting_Blink();
void Game();
void Game_Over();
float Get_Speed_Game(int minSpeed, int maxSpeed);
void Interrupt_Stop_Button();

////////////////////////////////////////////////////////////////////////////////
// Setup
////////////////////////////////////////////////////////////////////////////////
void setup()
 {
    // Set pinMode Output for all LED
    for (int i = 0; i < LED_NUMBER; i++) {
        pinMode(LEDPinArray[i], OUTPUT);
    } // End For loop

    // Start Serial monitor
    //Serial.begin(9600);

    // Set buttons as input
    pinMode(BUTTON_PIN_PLAY, INPUT);
    //pinMode(buttonPinReset, INPUT);

    // Create and attach interrupt function (Interrupt_Stop_Button) to BUTTON_PIN_PLAY when pin Rising
    attachInterrupt(digitalPinToInterrupt(BUTTON_PIN_PLAY), Interrupt_Stop_Button, RISING);
}

////////////////////////////////////////////////////////////////////////////////
// Loop
////////////////////////////////////////////////////////////////////////////////
void loop()
 {
    // Total on board LED
    goal = 10;

    // Setup random speed game
    delaySpeed = Get_Speed_Game(MIN_SPEED, MAX_SPEED);

    // Get the 10% initial speed to subtract each goal reached\ {
    subtractValue = delaySpeed * 0.1;

    // Start waiting display
    Start_Waiting();

    // Display starting light
    Starting_Blink();

    // Start the game
    Game();

    // Display Game Over
    Game_Over();    
} // End loop

////////////////////////////////////////////////////////////////////////////////
// Start_Waiting
////////////////////////////////////////////////////////////////////////////////
void Start_Waiting() {

    // Set exitFlag to 0
    exitFlag                    =   false;
    unsigned long currentMillis =   0;
    unsigned long ledMillis     =   0;

    // Do while the start button isn't pressed
    do {
        currentMillis = millis();

        // Foreach LED: Check status. If status is low then turn it on. Else, turn it off
        for (int i = 0; i < LED_NUMBER; i++) {
            ledState = digitalRead(LEDPinArray[i]);
            if (ledState == LOW) {
                digitalWrite(LEDPinArray[i], HIGH);
            } else {
                digitalWrite(LEDPinArray[i], LOW);
            }
            // Delay after each LED (keep if necessary)
            while (millis() - ledMillis < 100) {
                // Wait
            }
            ledMillis = millis();
        } // end for loop
    } while(exitFlag == false); // end while loop
} // End Start_Waiting

////////////////////////////////////////////////////////////////////////////////
// Starting_Blink
////////////////////////////////////////////////////////////////////////////////
void Starting_Blink() {

    // Reset all LED statement
    for (int i = 0; i < LED_NUMBER; i++) {
        digitalWrite(LEDPinArray[i], LOW);
    } // End For loop

    // Pause
    delay(500);

    // Blink all LED 3 times
    for (int i = 0; i < 3; i++) {

        // Turn on LEDs
        for (int i = 0; i < LED_NUMBER; i++) {
            digitalWrite(LEDPinArray[i], HIGH);
        } // End For loop

        // Pause
        delay(500);

        // Turn off LEDs
        for (int i = 0; i < LED_NUMBER; i++) {
            digitalWrite(LEDPinArray[i], LOW);
        } // End For loop

        // Pause
        delay(500);
     } // End For loop
} // End Starting_Blink

////////////////////////////////////////////////////////////////////////////////
// Game
////////////////////////////////////////////////////////////////////////////////
void Game() {
    
    // Set exitFlag to 0
    exitFlag = false;

    // Set score to 0
    score = 0;

    // Turn on last LED
    digitalWrite(LEDPinArray[9], HIGH);

    // Start game
    do {

        // Foreach led under the goal
        for (int i = 0; i < goal; i++) {
            
            // If score is reached, exit for loop and do while loop
            if( score == LED_NUMBER - 1 ) {
                exitFlag = true;
                break;
            } // End if

            // if the stop button was pressed at good time:
            // - Highlight the goal -1 led.
            // - Then, set the flag to 0
            // - Then, decrease the goal
            // - Then increase the score
            // - Then break the for loop
            if( i == goal - 1 && exitFlag == true) {
                digitalWrite(LEDPinArray[i - 1], HIGH);
                exitFlag = false;
                goal--;
                score++;
                break;
            } // End if

            // Else if the button was pressed but the goal is not reached, 
            // or if the button wasn't pressed but the goal is reached,
            // break the for loop and go to the Gameover "screen"
            else if( (i != goal - 1 && exitFlag == true) || (i == goal - 1)) {
                exitFlag = true;
                break;
            } // End Else if

            // Blink the current LED
            digitalWrite(LEDPinArray[i], HIGH);

            // Delay using millis
            unsigned long currentMillis = millis();
            while (millis() - currentMillis < delaySpeed) {
                // Wait
            }    

            digitalWrite(LEDPinArray[i],LOW);
        } // End For loop

        delaySpeed= delaySpeed - subtractValue;
     } while (exitFlag == false); // End do while loop
} // End Game


////////////////////////////////////////////////////////////////////////////////
// Game_Over
////////////////////////////////////////////////////////////////////////////////
void Game_Over() {
    exitFlag = false;

    // Reset all LED statement
    for (int i = 0; i < LED_NUMBER; i++) {
        digitalWrite(LEDPinArray[i], LOW);
    } // End For loop

    // Delay
    unsigned long currentMillis = millis();
    while (millis() - currentMillis < 500) {
        // Wait
    }

    for (int i = 0; i < 3; i++) {
        // Turn on LEDs
        for (int i = (LED_NUMBER - score - 1); i < LED_NUMBER; i++) {
            digitalWrite(LEDPinArray[i], HIGH);
        } // End For loop

        // Delay
        while (millis() - currentMillis < 500) {
            // Wait
        }
        currentMillis = millis();

        // Turn off LEDs
        for (int i = (LED_NUMBER - score - 1); i < LED_NUMBER; i++) {
            digitalWrite(LEDPinArray[i], LOW);
        } // End For loop

        // Delay
        while (millis() - currentMillis < 500) {
            // Wait
        }
        currentMillis = millis();
    }

} // End Game_Over

////////////////////////////////////////////////////////////////////////////////
// Get_Speed_Game
// Param:   int minSpeed    :   Minimal speed delay for the game
//          int maxSpeed    :   Maximal speed delay for the game
// Return:  random          :   Random value between minSpeed and maxSpeed
////////////////////////////////////////////////////////////////////////////////
float Get_Speed_Game(int minSpeed, int maxSpeed) {
    return random(minSpeed, maxSpeed); 
} // End Get_Speed_Game

////////////////////////////////////////////////////////////////////////////////
// Interrupt_Stop_Button
////////////////////////////////////////////////////////////////////////////////
void Interrupt_Stop_Button() {
    exitFlag = true;
} // End Interrupt_Stop_Button

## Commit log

2023-11-14 Add KiCad files
    [ATMegaSpin.kicad_pcb, ATMegaSpin.kicad_sch, ED281DT.step]
2023-11-15 Update KiCad files
    [1066.step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]
2023-11-15 Adapt tree
    [ATMegaSpin.kicad_pcb, ATMegaSpin.kicad_sch, ATMegaSpin.step]
2023-11-15 Kicad updated
    [ATMegaSpin.kicad_pcb, ATMegaSpin.kicad_sch]
2023-11-15 Update Kicad
    [ATMegaSpin-B_Cu.gbr, ATMegaSpin-B_Mask.gbr, ATMegaSpin-B_Paste.gbr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]
2023-11-16 Update CAD
    [ATMEGA328P-PU.ipt, ATMEGA328P-PU.step, ATMegaSpin.ipt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]
2023-11-17 Manage Tree
    [SwitchOnOff.stl]
2023-11-17 Modify Inventor Files
    [BottomBox.0003.ipt, BottomBox.0005.ipt, BottomBox.ipt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]
2023-11-17 Update invntor
    [BottomBox.0005.ipt, BottomBox.0006.ipt, BottomBox.ipt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]
2023-11-20 Modify box
    [BottomBox.0006.ipt, BottomBox.0007.ipt, BottomBox.ipt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]
2023-11-22 Update Box
    [BottomBox.0007.ipt, BottomBox.0008.ipt, BottomBox.ipt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]
2023-11-22 Update files
    [ATMegaSpin-B_Cu.gbr, ATMegaSpin-B_Mask.gbr, ATMegaSpin-B_Paste.gbr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]
2023-11-22 Update 3D View + schematic + GERBER files
    [ATMegaSpin-B_Cu.gbr, ATMegaSpin-B_Mask.gbr, ATMegaSpin-B_Paste.gbr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]
2023-11-22 Enable Release 1.0.0-beta
    [BottomBox.stl, Ensemble2.0009.iam, Ensemble2.0010.iam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]
2023-12-05 Replace Delay by Millis()
    [Spin.ino]
2023-12-14 Update prototype picture
2024-01-26 👌 IMPROVE: Modifying the box
    [BottomBox.0008.ipt, BottomBox.0009.ipt, BottomBox.ipt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]

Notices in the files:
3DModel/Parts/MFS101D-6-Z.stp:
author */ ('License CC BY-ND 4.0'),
